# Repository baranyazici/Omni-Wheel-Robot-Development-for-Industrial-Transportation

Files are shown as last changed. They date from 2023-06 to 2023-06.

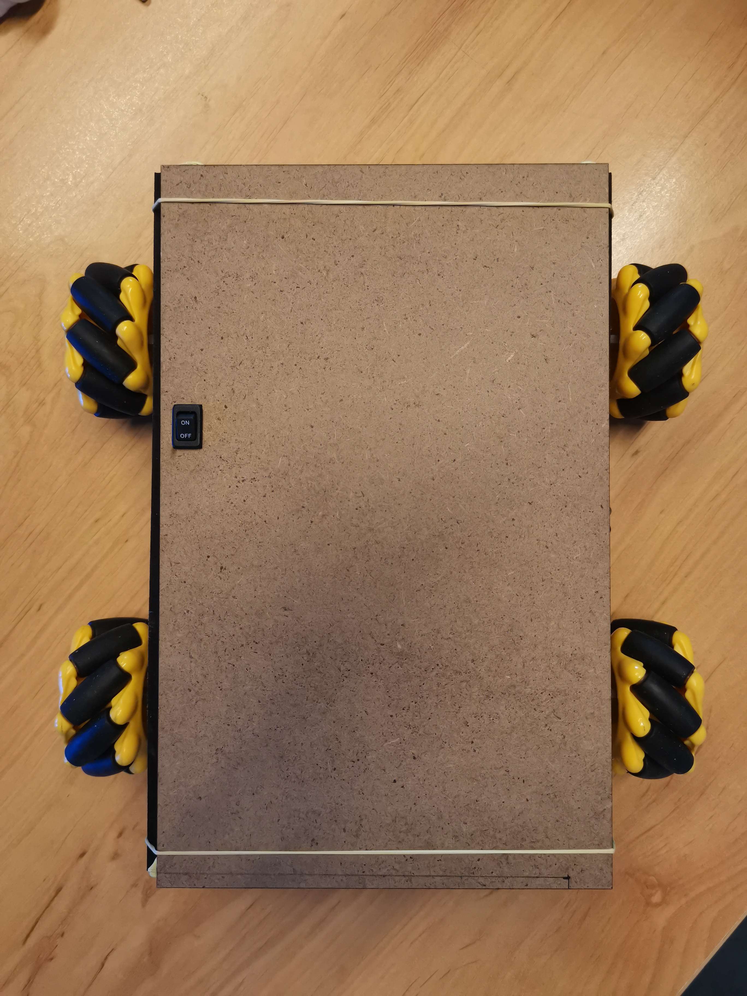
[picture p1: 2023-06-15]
Photos/robot_foto_8.jpeg

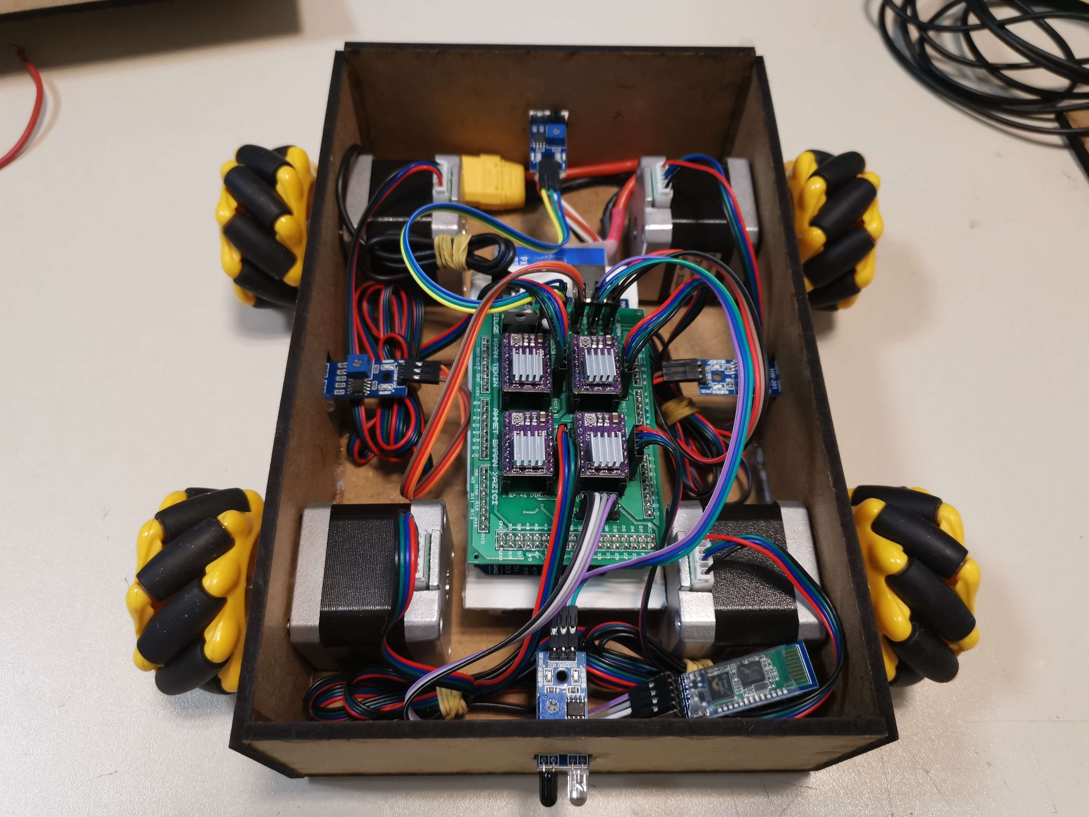
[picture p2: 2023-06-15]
Photos/robot_foto_3.jpeg

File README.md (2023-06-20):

> **_PROJECT DESCRIPTION:_** The Omni-Wheel Robot, which can be driven without hitting obstacles, was developed to be used in transportation conditions that may be required in industrial spaces, in the Özyeğin University Electrical and Electronics Engineering department graduation project was produced by Ahmet Baran Yazıcı and Bilge Kaan Tekin.

## Components

* `Arduino MEGA                              x1`
* `NEMA17HS4401 Stepper Motor                x4`
* `DRV8825 Stepper Motor Driver Card         x4`
* `HC05 Ardunio Bluetooth Module             x1`
* `LM7805 Voltage Regulator                  x1`
* `100uF Capacitor                           x4`
* `100nF Capacitor                           x1`
* `47uF 25V Capacitor                        x1`
* `60 mm Mecanum Wheel                       x4`
* `3-Cell 11.1V 3700mAh Li-Polymer Battery   x1`
* `CNC Manufactured Couplings                x4`
* `HW-201 IR Obstacle Avoiding Sensor        x4`

*******************

Here is the [video](https://youtu.be/IAhqdZXjo0E) where the robot is controlled via the mobile application, all commands are performed, and the direction of rotation of the wheels is shown according to the commands.

# Omni Wheel Robot Development for Industrial Transportation
devs_with_robot

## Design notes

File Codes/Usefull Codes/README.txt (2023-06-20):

In this folder, you can find the Arduino codes which we used during the development of the project. To achieve the Final Code, we took advantage of the codes in this folder.
Some of them has their comment lines.

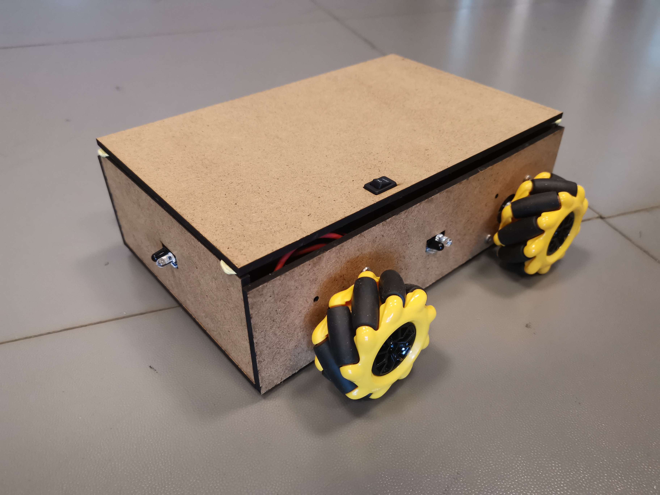
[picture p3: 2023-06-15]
Photos/robot_foto_1.jpeg

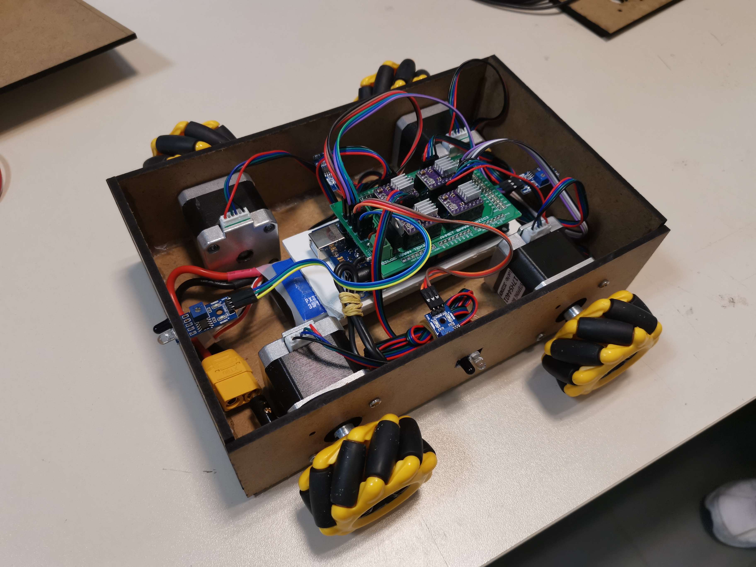
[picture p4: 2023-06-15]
Photos/robot_foto_7.jpeg

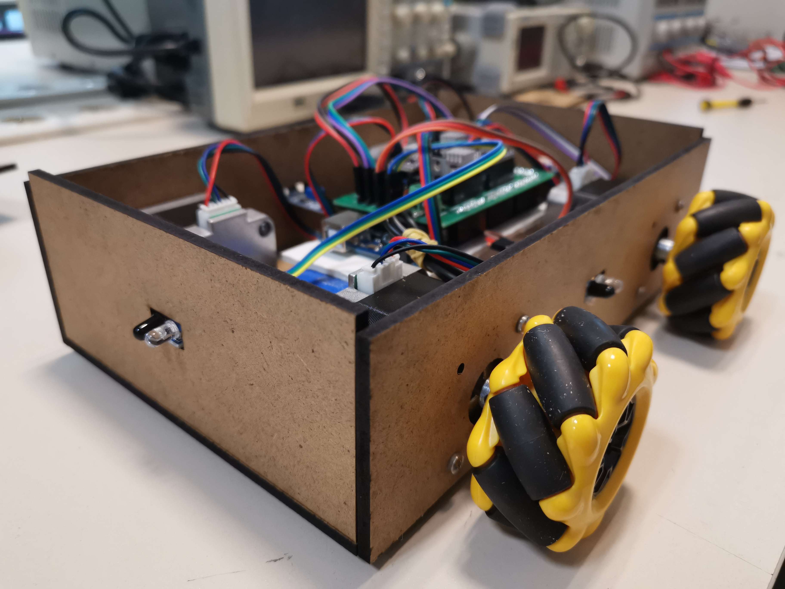
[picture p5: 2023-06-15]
Photos/robot_foto_6.jpeg

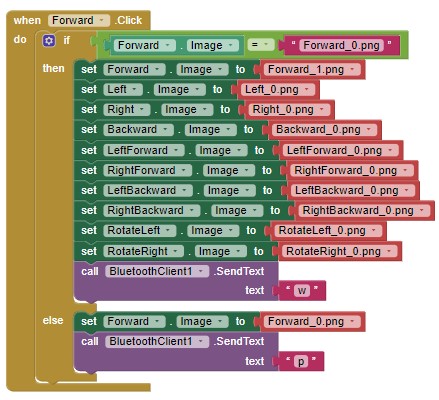
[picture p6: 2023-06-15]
Photos/Forward_mobile_app.jpg

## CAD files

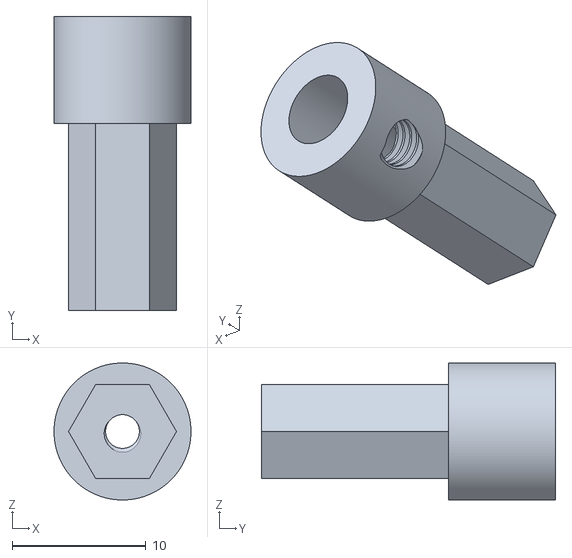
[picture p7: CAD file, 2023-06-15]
Omni Wheel Shaft/omni_wheel_saft.stl
10.2 x 22.0 x 10.2

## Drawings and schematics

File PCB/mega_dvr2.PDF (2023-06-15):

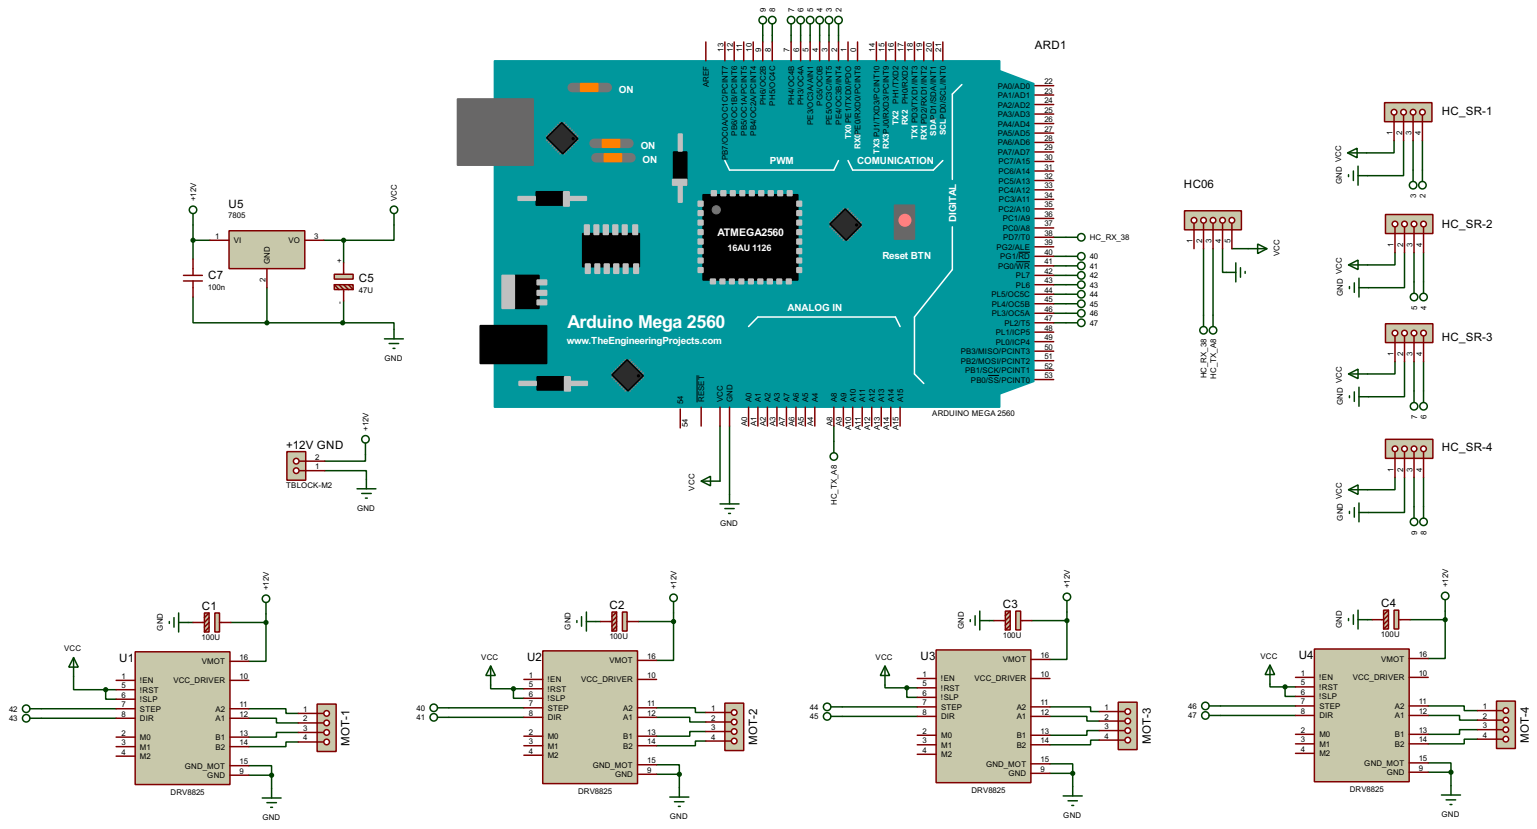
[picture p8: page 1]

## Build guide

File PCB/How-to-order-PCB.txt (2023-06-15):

How to Order PCB

Please refer to:
https://docs.easyeda.com/en/PCB/Order-PCB

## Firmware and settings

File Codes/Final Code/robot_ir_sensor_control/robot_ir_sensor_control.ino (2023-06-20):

//Graduation: 24.06.2023
//Bilge Kaan Tekin & Ahmet Baran Yazıcı

#include <SoftwareSerial.h> //including the SoftwareSerial library for Bluetooth communication
#include <AccelStepper.h> //including the AccelStepper libraryin
#include <Ultrasonic.h>

SoftwareSerial Bluetooth(A8, 38); //(RX,TX)Arduino RX pin connected to HC05 TX pin

#define RIGHTOUT 3  //defining the IR Sensor's OUT pins for right
#define BACKOUT 5   //back
#define LEFTOUT 7   //left
#define FRONTOUT 9  //front

//defining the stepper motors and related pins
AccelStepper left_front(1, 42, 43); //(type:driver, STEP, DIR) ->Stepper Motor 1
AccelStepper right_front(1, 40, 41); //->Stepper Motor 2
AccelStepper right_back(1, 44, 45); //->Stepper Motor 3
AccelStepper left_back(1, 46, 47); //->Stepper Motor 4

int wheel_speed = 600; //setting the wheel speed as integer
String data_in; //the string input coming from the Bluetooth
bool isMoving = false; //boolean function for runSpeed() command

void setup() {
  //pin Mode spesification for IR sensors as inputs
  pinMode(RIGHTOUT, INPUT);
  pinMode(BACKOUT, INPUT);
  pinMode(LEFTOUT, INPUT);
  pinMode(FRONTOUT, INPUT);

  //setting the maximum speeds of motors
  left_back.setMaxSpeed(1000);
  left_front.setMaxSpeed(1000);
  right_back.setMaxSpeed(1000);
  right_front.setMaxSpeed(1000);
  Bluetooth.begin(9600);
}

void loop() {
  //an if statement for avoiding obstacle
  if ((digitalRead(RIGHTOUT) == 0) || (digitalRead(BACKOUT) == 0) || (digitalRead(LEFTOUT) == 0) || (digitalRead(FRONTOUT) == 0)) {
    stop_moving();
    delay(1000);
    if ((digitalRead(RIGHTOUT) == 0)) {
      control_sideways_left();
      stop_moving();
    }
    else if ((digitalRead(BACKOUT) == 0)) {
      control_forward();
      stop_moving();
    }
    else if ((digitalRead(LEFTOUT) == 0)) {
      control_sideways_right();
      stop_moving();
    }
    else if ((digitalRead(FRONTOUT) == 0)) {
      control_backward();
      stop_moving();
    }
  }

  while (Bluetooth.available()) {       //checks if the Bluetooth is available
    data_in = Bluetooth.readString();   //the word written from the phone will be stored in the "data_in" string

    if (data_in == "w") {               //if we write "w" in our phone,
      go_forward();                     //code will run the "go_forward() functi
      isMoving = true;                  //by assigning isMoving as true, code will perform runSpeed() function
    }
    else if (data_in == "s") {          //if user writes "s" from phone's terminal monitor
      go_backward();                    //code will run the "go_backward()" function
      isMoving = true;
    }
    else if (data_in == "d") {
      go_sideways_right();
      isMoving = true;
    }
    else if (data_in == "a") {
      go_sideways_left();
      isMoving = true;
    }
    else if (data_in == "e") {
      rotate_right();
      isMoving = true;
    }
    else if (data_in == "q") {
      rotate_left();
      isMoving = true;
    }
    else if (data_in == "wd") {
      go_right_forward();
      isMoving = true;
    }
    else if (data_in == "sd") {
      go_right_backward();
      isMoving = true;
    }
    else if (data_in == "wa") {
      go_left_forward();
      isMoving = true;
    }
    else if (data_in == "sa") {
      go_left_backward();
      isMoving = true;
    }
    else if (data_in == "p") {
      stop_moving();
      isMoving = false;
    }
  }

  if (isMoving) {
    left_front.runSpeed();
    left_back.runSpeed();
    right_front.runSpeed();
    right_back.runSpeed();
  }
}

//control and action codes
void control_backward() {
  left_front.setCurrentPosition(0);
  left_back.setCurrentPosition(0);
  right_back.setCurrentPosition(0);
  right_front.setCurrentPosition(0);
  while ((left_front.currentPosition() != 100) && (left_back.currentPosition() != 100) &&
         (right_back.currentPosition() != -100) && (right_front.currentPosition() != -100)) {
    left_front.setSpeed(wheel_speed / 2);
    left_back.setSpeed(wheel_speed / 2);
    right_back.setSpeed(-wheel_speed / 2);
    right_front.setSpeed(-wheel_speed / 2);
    left_front.runSpeed();
    left_back.runSpeed();
    right_front.runSpeed();
    right_back.runSpeed();
  }
}

void control_forward() {
  left_front.setCurrentPosition(0);
  left_back.setCurrentPosition(0);
  right_back.setCurrentPosition(0);
  right_front.setCurrentPosition(0);
  while ((left_front.currentPosition() != -100) && (left_back.currentPosition() != -100) &&
         (right_back.currentPosition() != 100) && (right_front.currentPosition() != 100)) {
    left_front.setSpeed(-wheel_speed / 2);
    left_back.setSpeed(-wheel_speed / 2);
    right_back.setSpeed(wheel_speed / 2);
    right_front.setSpeed(wheel_speed / 2);
    left_front.runSpeed();
    left_back.runSpeed();
    right_front.runSpeed();
    right_back.runSpeed();
  }
}

void control_sideways_right() {
  left_front.setCurrentPosition(0);
  left_back.setCurrentPosition(0);
  right_back.setCurrentPosition(0);
  right_front.setCurrentPosition(0);
  while ((left_front.currentPosition() != -100) && (left_back.currentPosition() != 100) &&
         (right_back.currentPosition() != 100) && (right_front.currentPosition() != -100)) {
    left_front.setSpeed(-wheel_speed / 2);
    left_back.setSpeed(wheel_speed / 2);
    right_back.setSpeed(wheel_speed / 2);
    right_front.setSpeed(-wheel_speed / 2);
    left_front.runSpeed();
    left_back.runSpeed();
    right_front.runSpeed();
    right_back.runSpeed();
  }
}

void control_sideways_left() {
  left_front.setCurrentPosition(0);
  left_back.setCurrentPosition(0);
  right_back.setCurrentPosition(0);
  right_front.setCurrentPosition(0);
  while ((left_front.currentPosition() != 100) && (left_back.currentPosition() != -100) &&
         (right_back.currentPosition() != -100) && (right_front.currentPosition() != 100)) {
    left_front.setSpeed(wheel_speed / 2);
    left_back.setSpeed(-wheel_speed / 2);
    right_back.setSpeed(-wheel_speed / 2);
    right_front.setSpeed(wheel_speed / 2);
    left_front.runSpeed();
    left_back.runSpeed();
    right_front.runSpeed();
    right_back.runSpeed();
  }
}

void go_forward() {                     //the void function for go forward
  left_front.setSpeed(-wheel_speed/2);    //we set the necessary directions for each wheel
  left_back.setSpeed(-wheel_speed/2);     //in order to move the robot to the forward
  right_back.setSpeed(wheel_speed/2);     //(-) signs in front of the speed is for the direction
  right_front.setSpeed(wheel_speed/2);    //and for the speed, its using the int wheel_speed that is written before
}

void go_backward() {
  left_front.setSpeed(wheel_speed/2);
  left_back.setSpeed(wheel_speed/2);
  right_back.setSpeed(-wheel_speed/2);
  right_front.setSpeed(-wheel_speed/2);
}

void go_sideways_right() {
  left_front.setSpeed(-wheel_speed/2);
  left_back.setSpeed(wheel_speed/2);
  right_back.setSpeed(wheel_speed/2);
  right_front.setSpeed(-wheel_speed/2);
}

void go_sideways_left() {
  left_front.setSpeed(wheel_speed/2);
  left_back.setSpeed(-wheel_speed/2);
  right_back.setSpeed(-wheel_speed/2);
  right_front.setSpeed(wheel_speed/2);
}

void rotate_right() {
  left_front.setSpeed(-wheel_speed/2);
  left_back.setSpeed(-wheel_speed/2);
  right_back.setSpeed(-wheel_speed/2);
  right_front.setSpeed(-wheel_speed/2);
}

void rotate_left() {
  left_front.setSpeed(wheel_speed/2);
  left_back.setSpeed(wheel_speed/2);
  right_back.setSpeed(wheel_speed/2);
  right_front.setSpeed(wheel_speed/2);
}

void go_right_forward() {
  left_front.setSpeed(-wheel_speed/2);
  left_back.setSpeed(0);
  right_back.setSpeed(wheel_speed/2);
  right_front.setSpeed(0);
}

void go_right_backward() {
  left_front.setSpeed(0);
  left_back.setSpeed(wheel_speed/2);
  right_back.setSpeed(0);
  right_front.setSpeed(-wheel_speed/2);
}

void go_left_forward() {
  left_front.setSpeed(0);
  left_back.setSpeed(-wheel_speed/2);
  right_back.setSpeed(0);
  right_front.setSpeed(wheel_speed/2);
}

void go_left_backward() {
  left_front.setSpeed(wheel_speed/2);
  left_back.setSpeed(0);
  right_back.setSpeed(-wheel_speed/2);
  right_front.setSpeed(0);
}

void stop_moving() {
  left_front.setSpeed(0);
  left_back.setSpeed(0);
  right_back.setSpeed(0);
  right_front.setSpeed(0);
}

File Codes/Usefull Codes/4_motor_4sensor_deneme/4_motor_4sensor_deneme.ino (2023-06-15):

//Bilge Kaan Tekin & Ahmet Baran Yazıcı

#include <SoftwareSerial.h> //including the SoftwareSerial library for Bluetooth communication
#include <AccelStepper.h> //including the AccelStepper library 
#include "NewPing.h"


SoftwareSerial Bluetooth(A8, 38); //(RX,TX)Arduino RX pin connected to HC05 TX pin

#define TRIGPIN1 3
#define ECHOPIN1 2
#define TRIGPIN2 5
#define ECHOPIN2 4
#define TRIGPIN3 7
#define ECHOPIN3 6
#define TRIGPIN4 9
#define ECHOPIN4 8

#define MAX_DISTANCE 900

NewPing right1(TRIGPIN1, ECHOPIN1, MAX_DISTANCE);
NewPing back2(TRIGPIN2, ECHOPIN2, MAX_DISTANCE);
NewPing left3(TRIGPIN3, ECHOPIN3, MAX_DISTANCE);
NewPing front4(TRIGPIN4, ECHOPIN4, MAX_DISTANCE);

float duration, distance_right1, distance_back2, distance_left3, distance_front4;
bool isMoving = false;

//defining the stepper motors and related pins
AccelStepper left_front(1, 42, 43); //(type:driver, STEP, DIR) ->Stepper Motor 1
AccelStepper right_front(1, 40, 41); //->Stepper Motor 2
AccelStepper right_back(1, 44, 45); //->Stepper Motor 3
AccelStepper left_back(1, 46, 47); //->Stepper Motor 4

int wheel_speed = 800; //setting the wheel speed as integer
String data_in; //the string input coming from the Bluetooth


void setup() {
  //setting the maximum speeds of motors
  left_back.setMaxSpeed(1500);
  left_front.setMaxSpeed(1500);
  right_back.setMaxSpeed(1500);
  right_front.setMaxSpeed(1500);

  //necessary Baud rates for Bluetooth communication
  //  Serial.begin(9600);
  Bluetooth.begin(9600);

}

void loop() {

  distance_right1 = right1.ping_cm();
  distance_back2 = back2.ping_cm();
  distance_left3 = left3.ping_cm();
  distance_front4 = front4.ping_cm();

  //  Serial.print("sağ sensör: ");
  //  Serial.println(distance_right1);
  //  Serial.print("arka sensör: ");
  //  Serial.println(distance_back2);
  //  Serial.print("sol sensör: ");
  //  Serial.println(distance_left3);
  //  Serial.print("ön sensör: ");
  //  Serial.println(distance_front4);
  //  Serial.println("---------------------------------");






  while (Bluetooth.available()) {       //checks if the Bluetooth is available
    data_in = Bluetooth.readString();   //the word written from the phone will be stored in the "data_in" string

    if (data_in == "w") {               //if we write "w" in our phone,
      go_forward();                     //code will run the "go_forward() functi
      isMoving = true;
      // Serial.println(data_in);          //to check if the code working properly, we printed the data_in on the serial monitor
    }
    else if (data_in == "s") {          //if user writes "s" from phone's terminal monitor
      go_backward();                    //code will run the "go_backward()" function
      isMoving = true;
      //   Serial.println(data_in);
    }
    else if (data_in == "d") {
      go_sideways_right();
      isMoving = true;
      //  Serial.println(data_in);
    }
    else if (data_in == "a") {
      go_sideways_left();
      isMoving = true;
      //  Serial.println(data_in);
    }
    else if (data_in == "e") {
      rotate_right();
      isMoving = true;
      // Serial.println(data_in);
    }
    else if (data_in == "q") {
      rotate_left();
      isMoving = true;
      //  Serial.println(data_in);
    }
    else if (data_in == "wd") {
      go_right_forward();
      isMoving = true;
      //   Serial.println(data_in);
    }
    else if (data_in == "sd") {
      go_right_backward();
      isMoving = true;
      //  Serial.println(data_in);
    }
    else if (data_in == "wa") {
      go_left_forward();
      isMoving = true;
      //  Serial.println(data_in);
    }
    else if (data_in == "sa") {
      go_left_backward();
      isMoving = true;
      //   Serial.println(data_in);
    }
    else if (data_in == "p") {
      stop_moving();
      isMoving = false;
      //   Serial.println(data_in);
    }

  }


  left_front.runSpeed();
  left_back.runSpeed();
  right_front.runSpeed();
  right_back.runSpeed();

  if ((distance_right1 < 10 && distance_right1 != 0) || (distance_back2 < 10 && distance_back2 != 0) || (distance_left3 < 10 && distance_left3 != 0) || (distance_front4 < 10 && distance_front4 != 0) ) {
    //    Serial.println("*****ROBOT DURDU!*****");
    left_back.setSpeed(0);
    left_front.setSpeed(0);
    right_back.setSpeed(0);
    right_front.setSpeed(0);
    isMoving = false;
    //    Serial.println(data_in);
  }


  if (isMoving) {
    left_front.runSpeed();
    left_back.runSpeed();
    right_front.runSpeed();
    right_back.runSpeed();
  }

}


void go_forward() {                     //the void function for go forward
  left_front.setSpeed(-wheel_speed);    //we set the necessary directions for each wheel
  left_back.setSpeed(-wheel_speed);     //in order to move the robot to the forward
  right_back.setSpeed(wheel_speed);     //(-) signs in front of the speed is for the direction
  right_front.setSpeed(wheel_speed);    //and for the speed, its using the int wheel_speed that is written before
}

void go_backward() {
  left_front.setSpeed(wheel_speed);
  left_back.setSpeed(wheel_speed);
  right_back.setSpeed(-wheel_speed);
  right_front.setSpeed(-wheel_speed);
}

void go_sideways_right() {
  left_front.setSpeed(-wheel_speed);
  left_back.setSpeed(wheel_speed);
  right_back.setSpeed(wheel_speed);
  right_front.setSpeed(-wheel_speed);
}

void go_sideways_left() {
  left_front.setSpeed(wheel_speed);
  left_back.setSpeed(-wheel_speed);
  right_back.setSpeed(-wheel_speed);
  right_front.setSpeed(wheel_speed);
}

void rotate_right() {
  left_front.setSpeed(-wheel_speed);
  left_back.setSpeed(-wheel_speed);
  right_back.setSpeed(-wheel_speed);
  right_front.setSpeed(-wheel_speed);

}

void rotate_left() {
  left_front.setSpeed(wheel_speed);
  left_back.setSpeed(wheel_speed);
  right_back.setSpeed(wheel_speed);
  right_front.setSpeed(wheel_speed);
}

void go_right_forward() {
  left_front.setSpeed(-wheel_speed);
  left_back.setSpeed(0);
  right_back.setSpeed(wheel_speed);
  right_front.setSpeed(0);
}

void go_right_backward() {
  left_front.setSpeed(0);
  left_back.setSpeed(wheel_speed);
  right_back.setSpeed(0);
  right_front.setSpeed(-wheel_speed);
}

void go_left_forward() {
  left_front.setSpeed(0);
  left_back.setSpeed(-wheel_speed);
  right_back.setSpeed(0);
  right_front.setSpeed(wheel_speed);
}

void go_left_backward() {
  left_front.setSpeed(wheel_speed);
  left_back.setSpeed(0);
  right_back.setSpeed(-wheel_speed);
  right_front.setSpeed(0);
}

void stop_moving() {
  left_front.setSpeed(0);
  left_back.setSpeed(0);
  right_back.setSpeed(0);
  right_front.setSpeed(0);
}

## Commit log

2023-06-15 PCB Files Added
    [Gerber_BoardOutline.GKO, Gerber_BottomLayer.GBL, Gerber_BottomSolderMaskLayer.GBS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]
2023-06-15 Some of the files have renamed
    [omni_wheel_saft.stl]
